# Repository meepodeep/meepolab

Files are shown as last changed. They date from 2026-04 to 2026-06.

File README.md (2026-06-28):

# MeepoLab
## Beginner 25-key midi controller with velocity-sensitive keys and drum pads





## Why does this exist
I made this project because I have been recently getting into making music for my own games, but I got tired of using a keyboard to do everything, so when Hackclub Stasis started to exist, I decided to make this. 
midi controller
# How to build
## PCB
1. Lay out and solder all of the smd components to the board
2. Solder the jst connectors
3. Solder the teensy on with pin headers
4. Flash the meepolab_sketch.ino file onto the teensy using midi mode
## Wiring 2
1. Solder the wires of the 12 pin jst connectors to all of the key matrix tactile switches and plug them into the plugs with these numbers. wire the "bottom" tactile switches to be the ones furthest from the pivot of the key, and the "top" ones closest to the center of the key. ( DO THIS AFTER YOU MOUNT THEM )
2. The V and ground are the 2 pins on the tactile switches, not actual voltage and ground
3. 
4. Solder the rest of your inputs, potentiometer, slide pot to the other 12pin jst connectors and plug them into the plugs with these numbers
5. 
6. Solder these jst connectors to the piezo drum pad sensors  and plug them into the plugs with these numbers
7. 
8. Solder the leds to the led jst connectors and plug them into the plugs with these numbers



## Assembly
1. assemble the 4 parts of the main shell and backplate together
2. Insert a bearing into the hole of every key
3. 
4. Align all of the keys how they are supposed to be and push the rod through the case,  bearings and keys
5. insert all of the return springs in between the pegs on the case and every key
6. 
7.insert all of the tactile switches into their holes in their mounting brackets.

8. tape piezo sensors to the back of each drum pad square on the drum pad membrane and the leds from the first shift register to it as well, and then mount the drum pad membrane to the keyboard
9. 
10. Mount the octave rocker, first by inserting it into position, and then inserting the axel after
11. 
12. insert a keyswitch into each of the octave rocker keyswitch mounts square holes and then screw them in using m3 hardware
13.
14. insert the keyswitches for the shift pause/play and record buttons into their holes
15. 
16. insert the potentiometers into their holes and screw them down using the included nut, after inserting the potentiometer area accent
17. 
18. put on the potentiometer caps
19. insert the slide potentiometers and screw in using m3 hardware after inserting accents
20. 
21. put on fader caps
22. insert leds and cover with optional acrylic
23. \
24. connect the cable to the teensy and run it through the hole
25. Attach bottom with m3 hardware
26. 
27. put keycaps on keys if you want
28. 

# BOM

|Name |Purpose |Quantity|Total Cost (USD)|Link |Distributor|
|---|---|---|---|---|---|
|blue leds |wie cool ist das bitte (it look pretty)|1 |1.42 |https://www.aliexpress.us/item/3256805214023855.html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 |aliexpress |
|acrylic |optional led diffuse |1 |0.00 | |i have |
|keycap |capping keys |3 |0.00 | |i have |
|m3 hardware |hardware |1 |0.00 | |i have |
|mx keyswitches |buttons |5 |0.00 | |i have |
|tactile swtiches |For keys |3 |6.72 |https://www.aliexpress.us/item/2251832777534166.html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 |aliexpress |
|12pin jst |wiring keyswitches |3 |9.96 |https://www.aliexpress.us/item/3256811409118695.html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 |aliexpress |
|Jst Ph2.0 2pin |leds |2 |5.36 |https://www.aliexpress.us/item/3256809537971085.html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 |aliexpress |
|Pcb |wiring up everythign |5 |28.60 | |jlcpcb |
|Teensy 4.1 |microcontroller |1 |31.50 |https://www.robotshop.com/products/teensy-41-usb-microcontroller-development-board-no-pins |RobotShop  |
|micro b to usb cable|cable for output |1 |2.34 |https://www.aliexpress.us/item/3256811607885785.html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 |Aliexpress |
|45mm slide pot |faders |1 |2.63 |https://www.aliexpress.us/item/3256808869794293.html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 |Aliexpress |
|10k pot |dials |2 |3.94 |https://www.aliexpress.us/item/3256802975243588.html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 |Aliexpress |
|Piezo sensor 12mm |drum pads |1 |2.35 |https://www.aliexpress.us/item/3256806816727111.html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|Aliexpress |
|15x8mm spring |key return |3 |13.48 |https://www.aliexpress.us/item/3256807447886846.html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 |Aliexpress |
|6X10X3 bearing |key bearings |3 |13.95 |https://www.aliexpress.us/item/3256810378046508.html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 |aliexpress |
|74HC595S16-13 |shift register for leds |4 |1.44 |https://www.digikey.com/en/products/detail/diodes-incorporated/74HC595S16-13/24630355 |Digikey |
|RC0402FR-071ML |resistor for piezo |10 |0.03 |https://www.digikey.com/en/products/detail/yageo/RC0402FR-071ML/726515 |Digikey |
|CRT0805-BY-1500ELF  |Resistor for multiplexers |2 |0.74 |https://www.digikey.com/en/products/detail/bourns-inc/CRT0805-BY-1500ELF/2564111 |Digikey |
|1N4148WS |Key grid diode |70 |3.64 |https://www.digikey.com/en/products/detail/evvo/1N4148WS/21407535 |Digikey |
|MMSZ4684T1G |zener diode for piezo sensors |10 |0.79 |https://www.digikey.com/en/products/detail/onsemi/MMSZ4684T1G/919718 |Digikey |
|SD103AW-7-F |Schottky diode for piezo sensors |20 |1.60 |https://www.digikey.com/en/products/detail/diodes-incorporated/SD103AW-7-F/1306103 |Digikey |
|4.7 nf capacitor |Pcb |10 |2.81 |https://www.digikey.com/en/products/detail/murata-electronics/GRM31BR72J472KW01L/789415 |Digikey |
|0.1uf capacitor |pcb |10 |0.12 |https://www.digikey.com/en/products/detail/murata-electronics/GRM033C71C104KE14D/5026260 |Digikey |

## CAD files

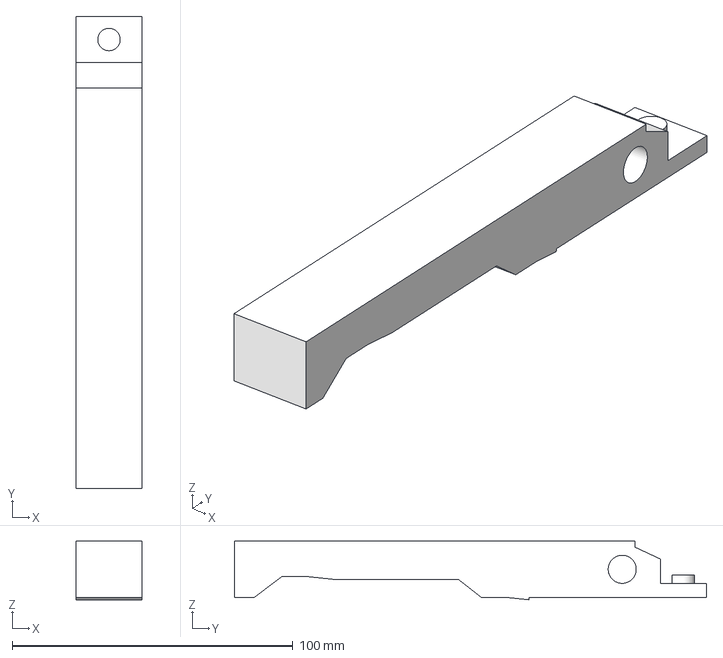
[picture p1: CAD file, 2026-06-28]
Cad Files/Key (16).3mf
23.6 x 168.0 x 20.8 mm

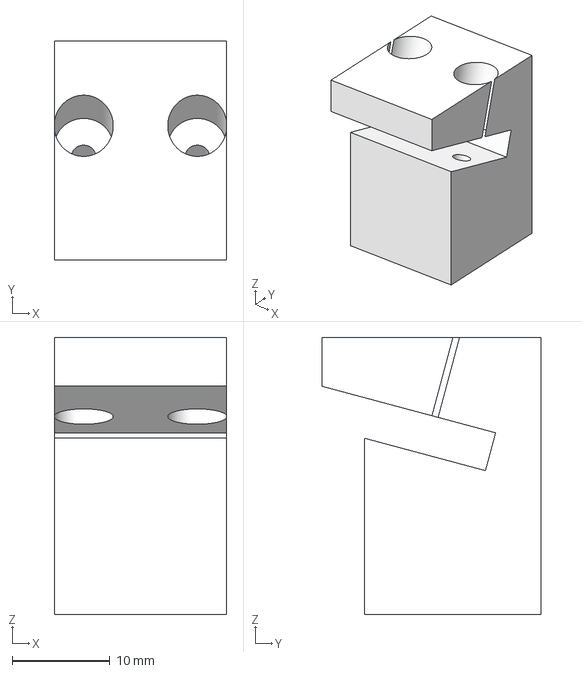
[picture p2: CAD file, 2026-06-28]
Key testing/Body188.3mf
17.6 x 22.4 x 28.3 mm

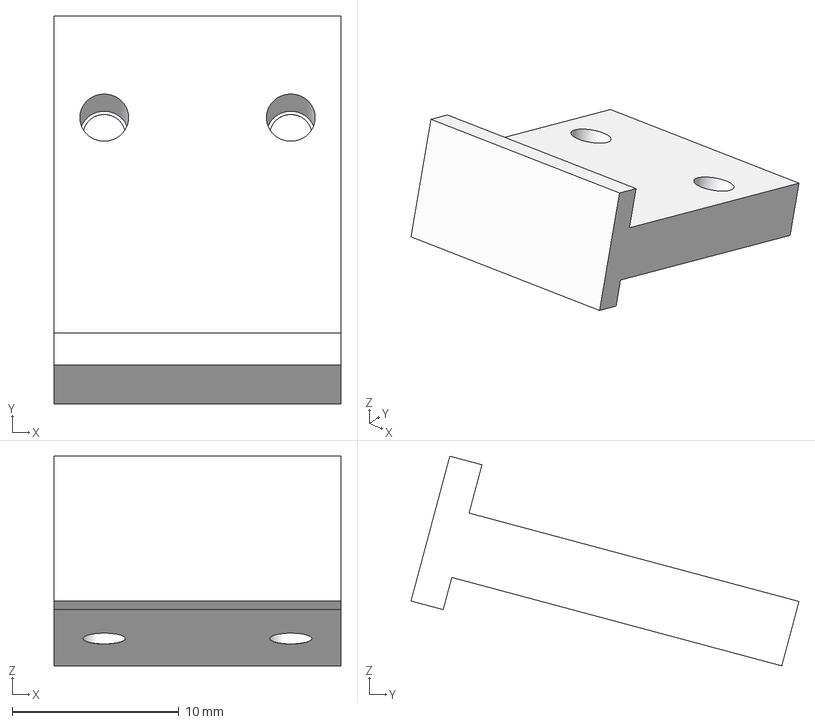
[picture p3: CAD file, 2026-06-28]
Key testing/tpu/Body208.3mf
17.2 x 23.3 x 12.6 mm

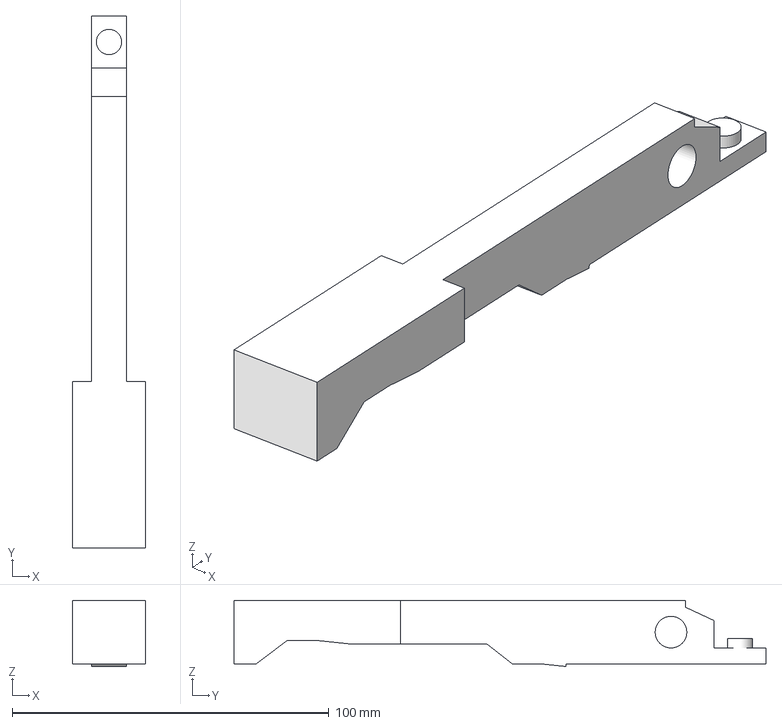
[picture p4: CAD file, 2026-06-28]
Cad Files/Key (11).3mf
23.2 x 168.0 x 20.8 mm

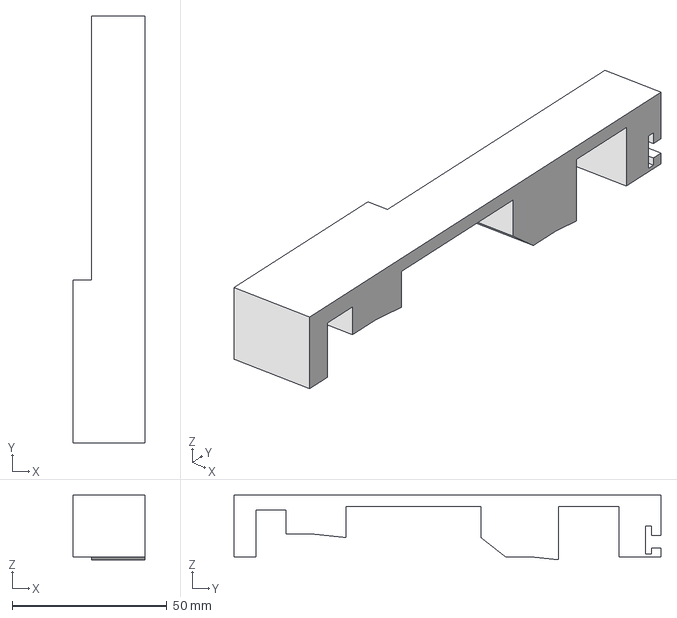
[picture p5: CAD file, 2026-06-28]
Key testing/Body31.3mf
23.2 x 138.0 x 20.8 mm

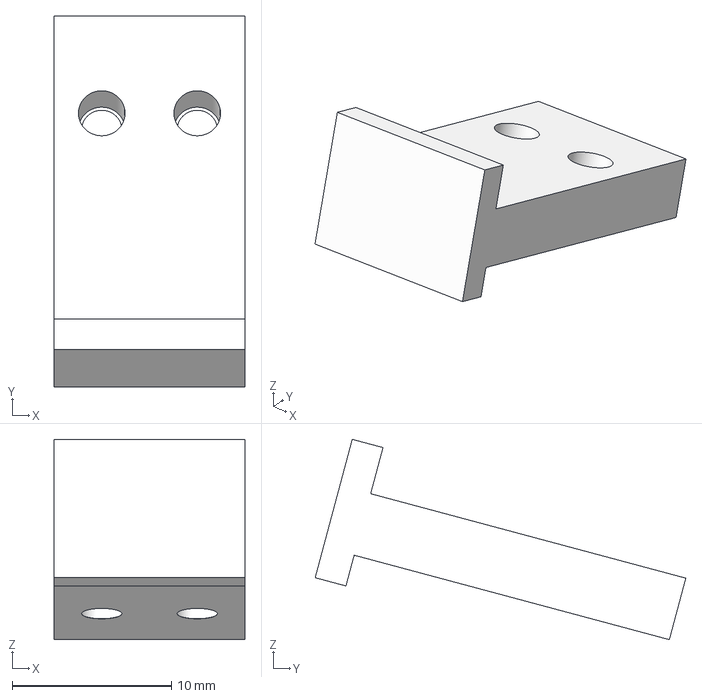
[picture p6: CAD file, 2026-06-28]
Key testing/tpu/Body205.3mf
12.0 x 23.3 x 12.6 mm

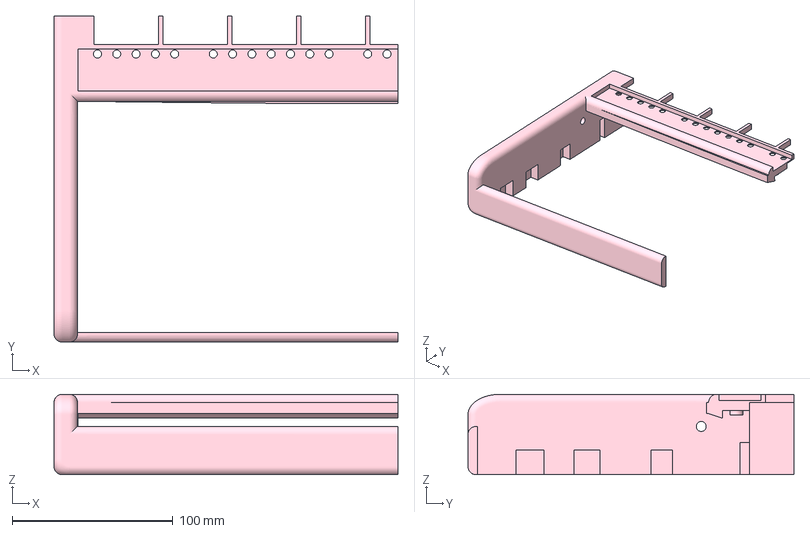
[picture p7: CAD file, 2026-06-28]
Cad Files/Case (3).3mf
213.8 x 202.6 x 50.0 mm

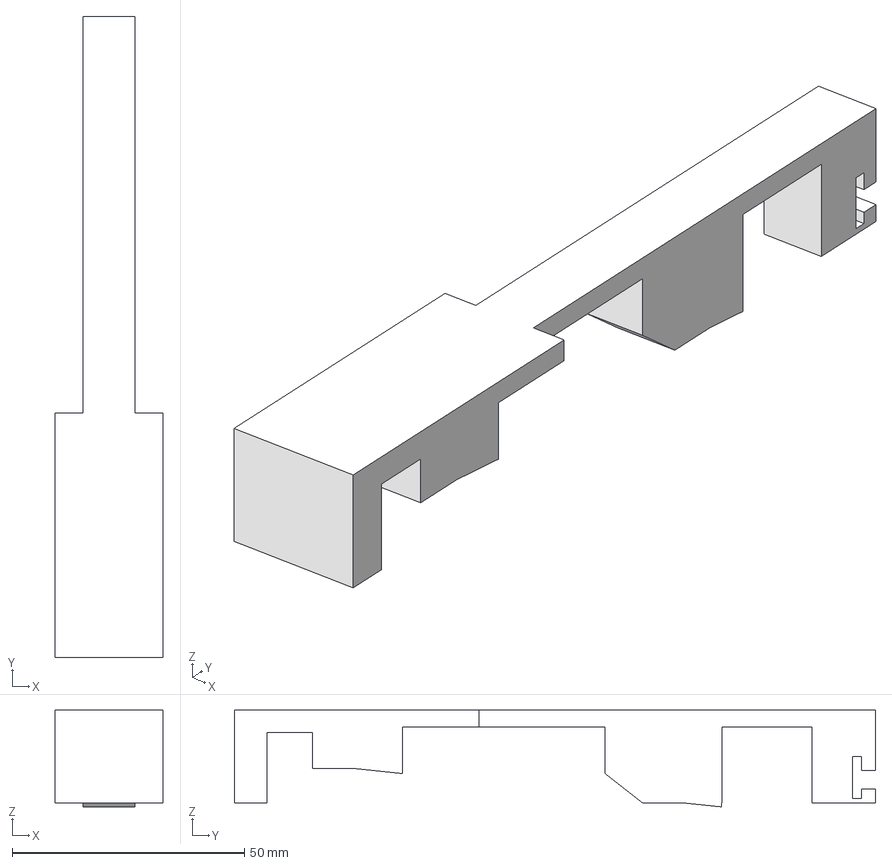
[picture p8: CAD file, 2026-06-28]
Key testing/Body29.3mf
23.2 x 138.0 x 20.8 mm

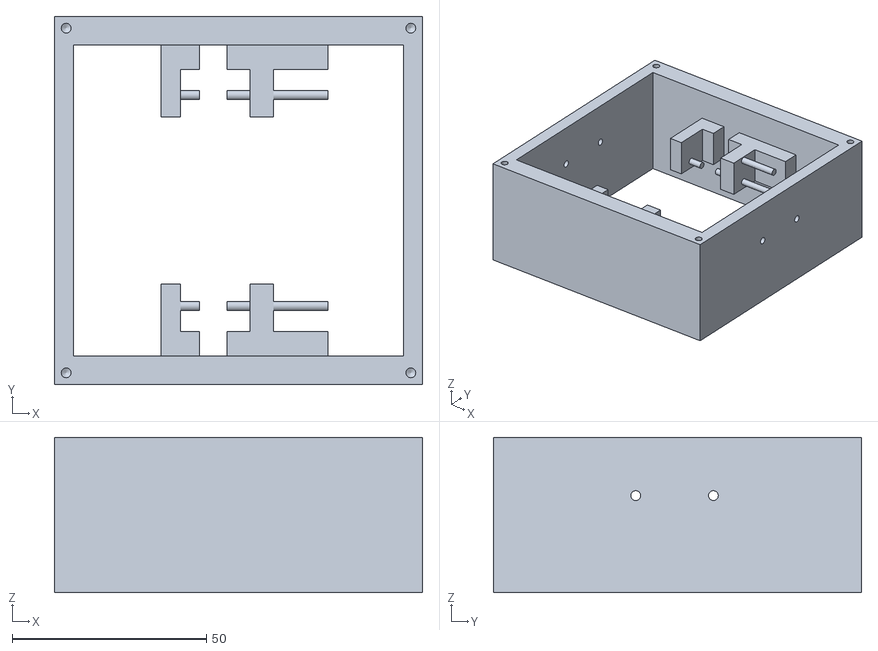
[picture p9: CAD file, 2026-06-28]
Cad Files/mounting plate.stl
94.8 x 94.8 x 40.0

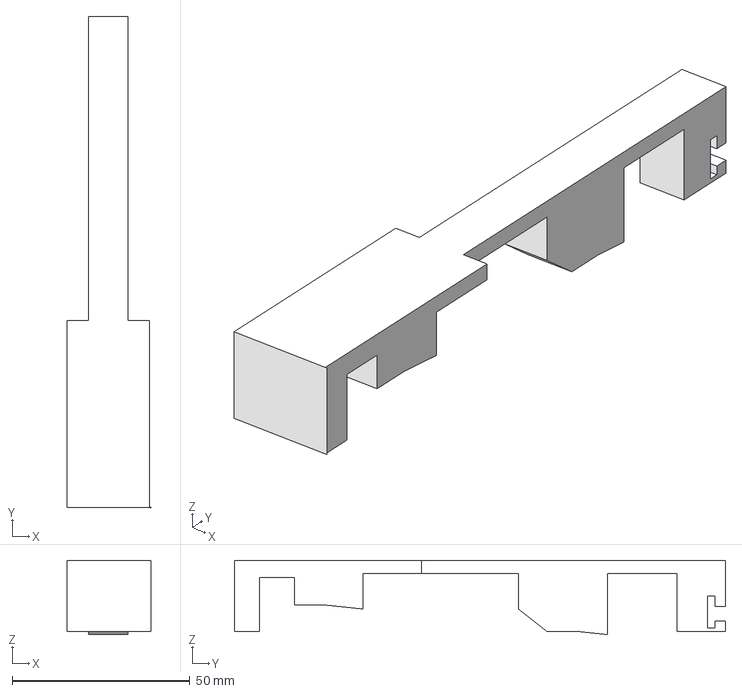
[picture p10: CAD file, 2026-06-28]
Key testing/Body34.3mf
23.6 x 138.0 x 20.8 mm

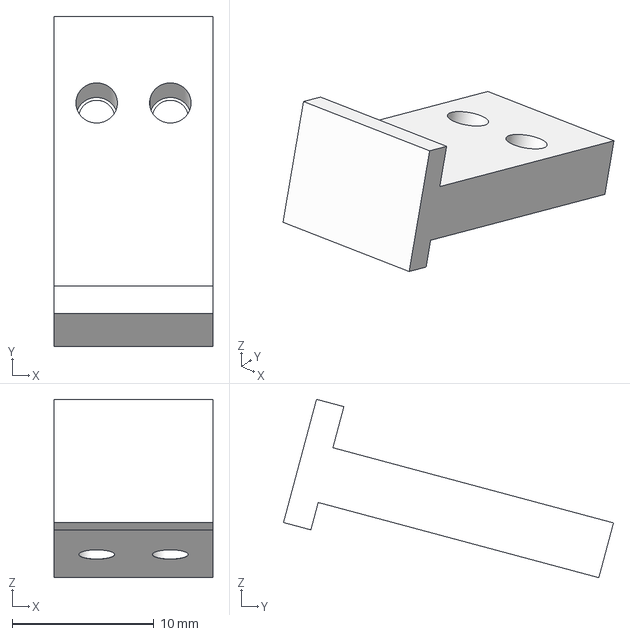
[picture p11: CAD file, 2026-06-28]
Key testing/tpu/Body212.3mf
11.2 x 23.3 x 12.6 mm

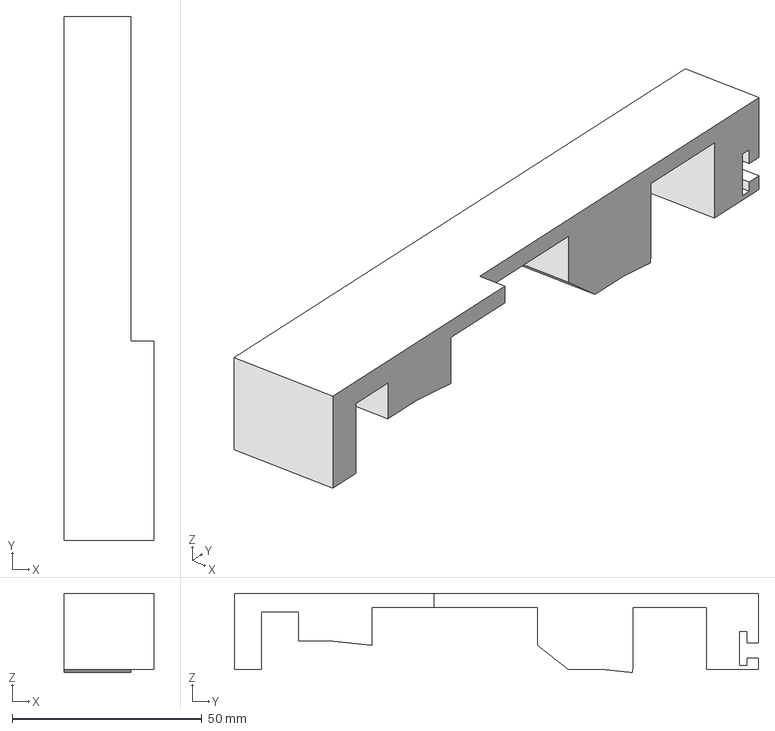
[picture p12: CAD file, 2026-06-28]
Key testing/Body40.3mf
23.6 x 138.0 x 20.8 mm

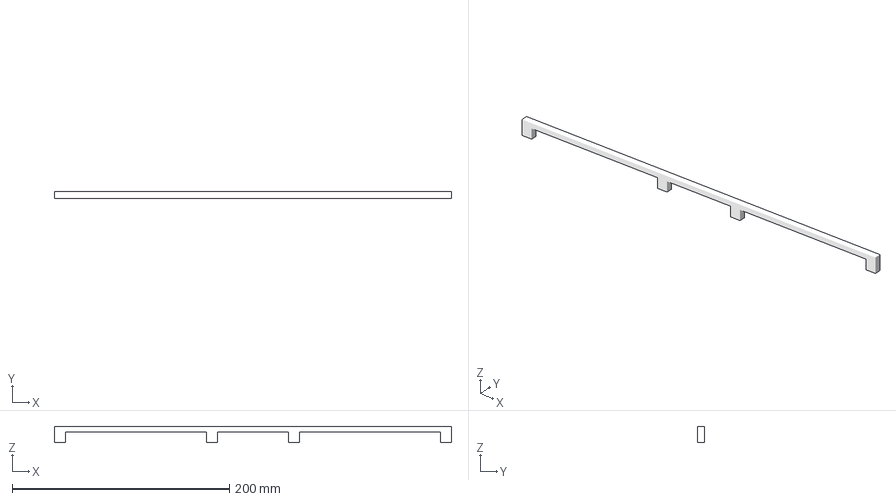
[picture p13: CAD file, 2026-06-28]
Cad Files/key help.3mf
365.4 x 6.00 x 15.0 mm

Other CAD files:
Key testing/tpu/Body197.3mf
Key testing/tpu/Body195.3mf
Cad Files/Key (15).3mf
Key testing/Body35.3mf
Key testing/tpu/Body203.3mf
Cad Files/Case (2).3mf
Cad Files/Key (1).3mf
Cad Files/Key (10).3mf
Cad Files/Key (12).3mf
Cad Files/Key (13).3mf
Cad Files/Key (14).3mf
Cad Files/Key (17).3mf
Cad Files/Key (18).3mf
Cad Files/Key (19).3mf
Cad Files/Key (2).3mf
Cad Files/Key (20).3mf
Cad Files/Key (21).3mf
Cad Files/Key (22).3mf
Cad Files/Key (23).3mf
Cad Files/Key (24).3mf
Cad Files/Key (3).3mf
Cad Files/Key (4).3mf
Cad Files/Key (5).3mf
Cad Files/Key (6).3mf
Cad Files/Key (7).3mf
Cad Files/Key (8).3mf
Cad Files/Key (9).3mf
Cad Files/Key reinforcement (1).3mf
Cad Files/Key reinforcement.3mf
Cad Files/Key.3mf
Cad Files/Keyplate.3mf
Cad Files/Meepolab v12_Meepolab v12_Acrylic.stl
Cad Files/Meepolab v12_Meepolab v12_BackPlate (1).stl
Cad Files/Meepolab v12_Meepolab v12_BackPlate (2).stl
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

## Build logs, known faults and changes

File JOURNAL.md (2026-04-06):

<!--
  This journal is auto generated by Stasis.
-->

# 4/5/2026 11 PM - worked on docs and the led code

_Time spent: 3h_

I started today by working on documentation. first made the basic info of the project, and then instructions for the build.



After finishing that up, i wrote the code that flashes the leds whenever you hit a key or one of the drum pads.






# 4/5/2026 2 AM - Finished Code

_Time spent: 2h_

I procrastinated a fuckton on this but i think im finally done. I started out by  defining an array of note velocities and making the key matrix velocity be set by that. 

After that i wrote 2 long ass match case statements that get the time of when the first and second switch for each key is pressed, subtracts them, and sets that to the velocity of the note, and that is the last of the code done.









# 4/4/2026 3 PM - worked on code

_Time spent: 3h_

After finishing up the case, I started on the code. I started out by initializing the multiplexers and the potentiometers.

After that, I tried to tackle the drum pads with this code I found from someone else online, trying to do the same thing, but I'm not sure if it will actually work.



And finally, I started working on the keys and the transpose button.








# 4/3/2026 8 PM - Worked on Cad model more

_Time spent: 3h_

After designing the basics of the midi controller
i started adding polish. I started by adding all of the buttons and a rocker switch for octave up and down.
And after doing that, i worked on where i was going to route all of the wires for the keys by adding gaps between the mounts.

Along with that, I rounded all of the corners, and added mounts for the backplate. And finaly, i added some visual flair with white details on the front. Time for firmware.........






# 4/3/2026 3 PM - Worked on the cad model for the midi controller

_Time spent: 5h_

Today I started working on the CAD model. I started by modelling the keys. 

After that, I added all of the buttons under the keys to be triggered at different points in the key travel to measure velocity, and the mounting for the bearings and axle in the keys. And after that, I added the mounting for all of the springs for the key return, and then the button mounts.

After finishing the keyboard, I worked on the drum pads, which will be printed in TPU or transparent PETG. 

After that, I modeled the mounts and knobs for the potentiometers and slide potentiometers. That is where I left off for the day


ALSO MY LAPSE COULDNT PROCESS BC IT WAS too long apparently






# 4/2/2026 8 PM - Worked on routing of drum pad and potentiometer wires

_Time spent: 1h_

Today, to start, I routed the rest of the traces for the potentiometers, and then I routed the circuit for the drum pad piezo sensors.


 After that, I went through all of the DRC errors and added some more thermal relief traces due to the ground planes being blocked and it is done!






# 4/1/2026 12 AM - Worked on Schematic and the layout

_Time spent: 3h_

To start out, continuing from my last journal, I made the keyboard matrix, and removed one of the multiplexers, shifting the keys from being potentiometer to tactile switch based, i still dont know what type of mechanical design im going to use, but i have a few ideas.

After that, i finished up the schematic by designing the circuit for the piezo sensor based drum pads.

and then i started laying out components for the actual board.






# 3/28/2026 4 AM - Worked on basic pcb design and research

_Time spent: 3h_

Today I started the project after seeing that the control surface library exists. and i started designing the pcb for a midi controller similar to the arturia minilab. I started by adding the multiplexers.

This is what I was hoping to use for potentiometers for the keys. and after that, i added all of the shift registers which are for the leds.

After doing all that, i realized, i cant use potentiometers for the keys. however, i do still need the multiplexers for other knobs, so it wasnt a complete waste of time. now i know i need to use a stacked button system with an array of buttons. and i will start work on that tomorrow.




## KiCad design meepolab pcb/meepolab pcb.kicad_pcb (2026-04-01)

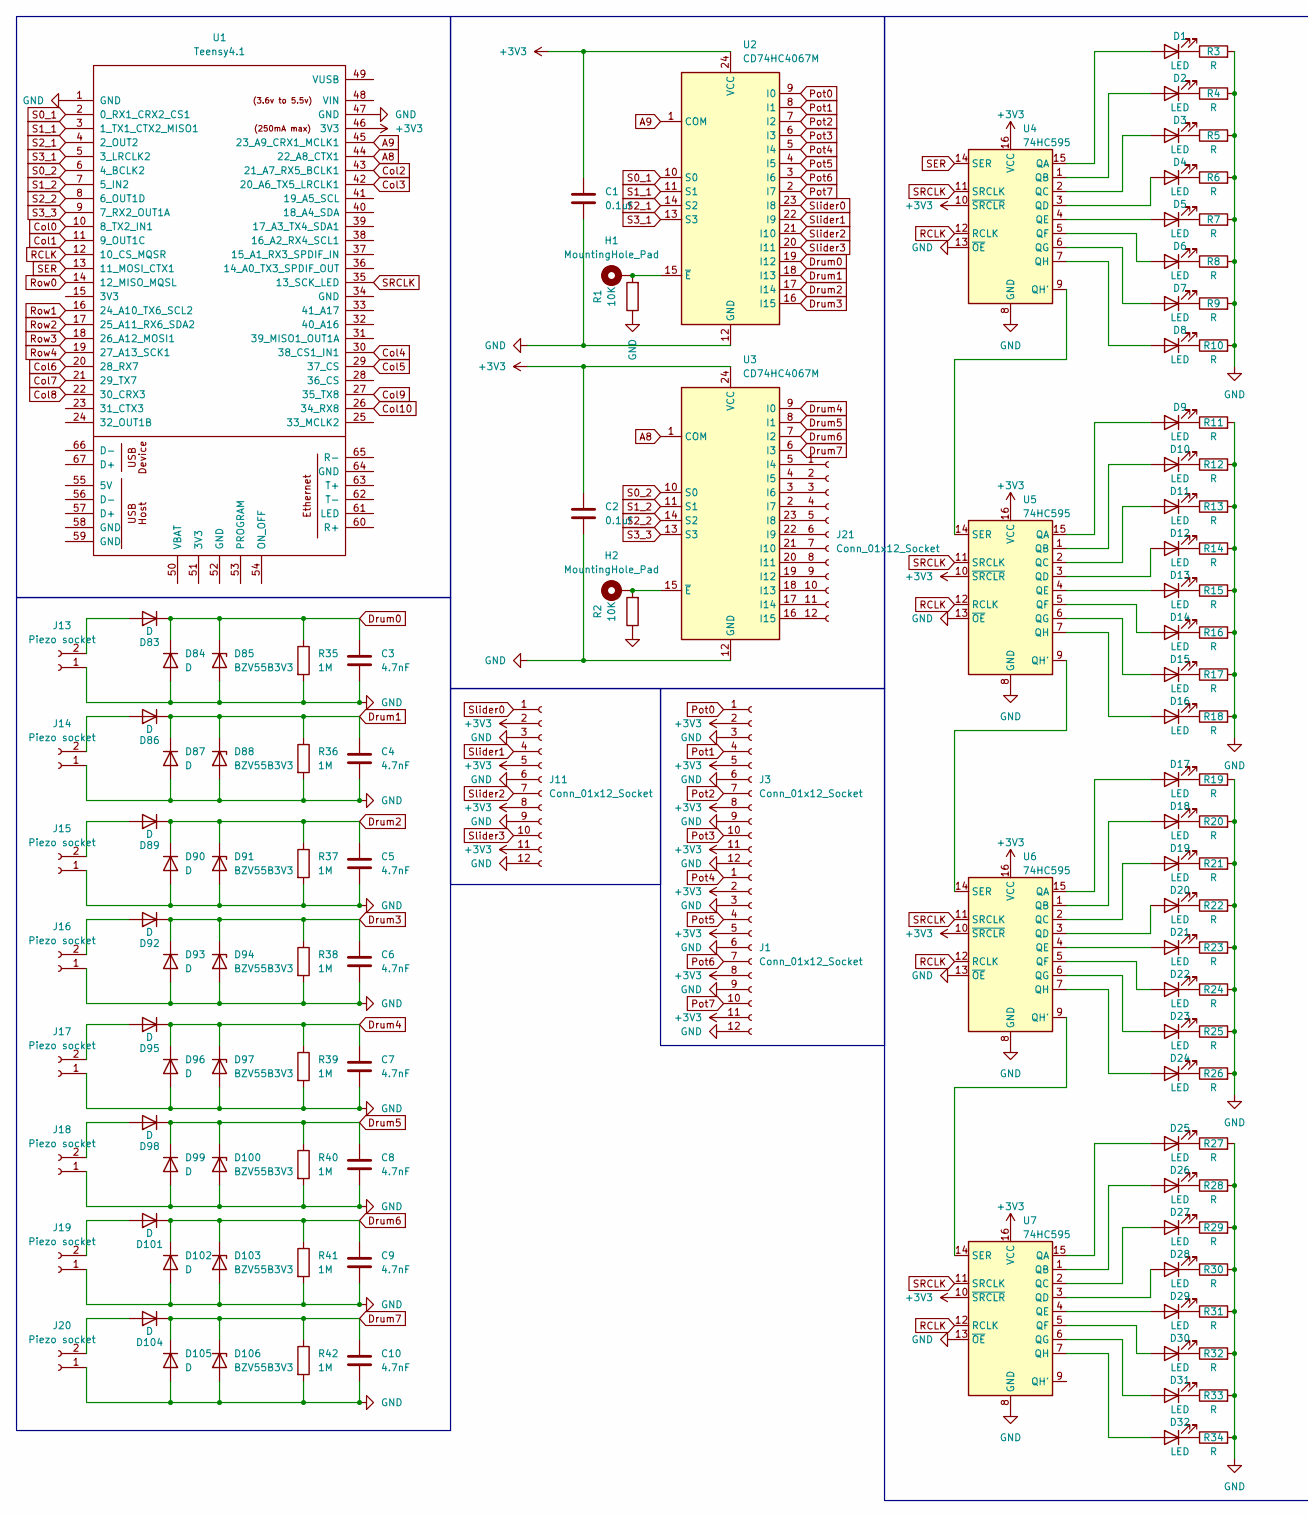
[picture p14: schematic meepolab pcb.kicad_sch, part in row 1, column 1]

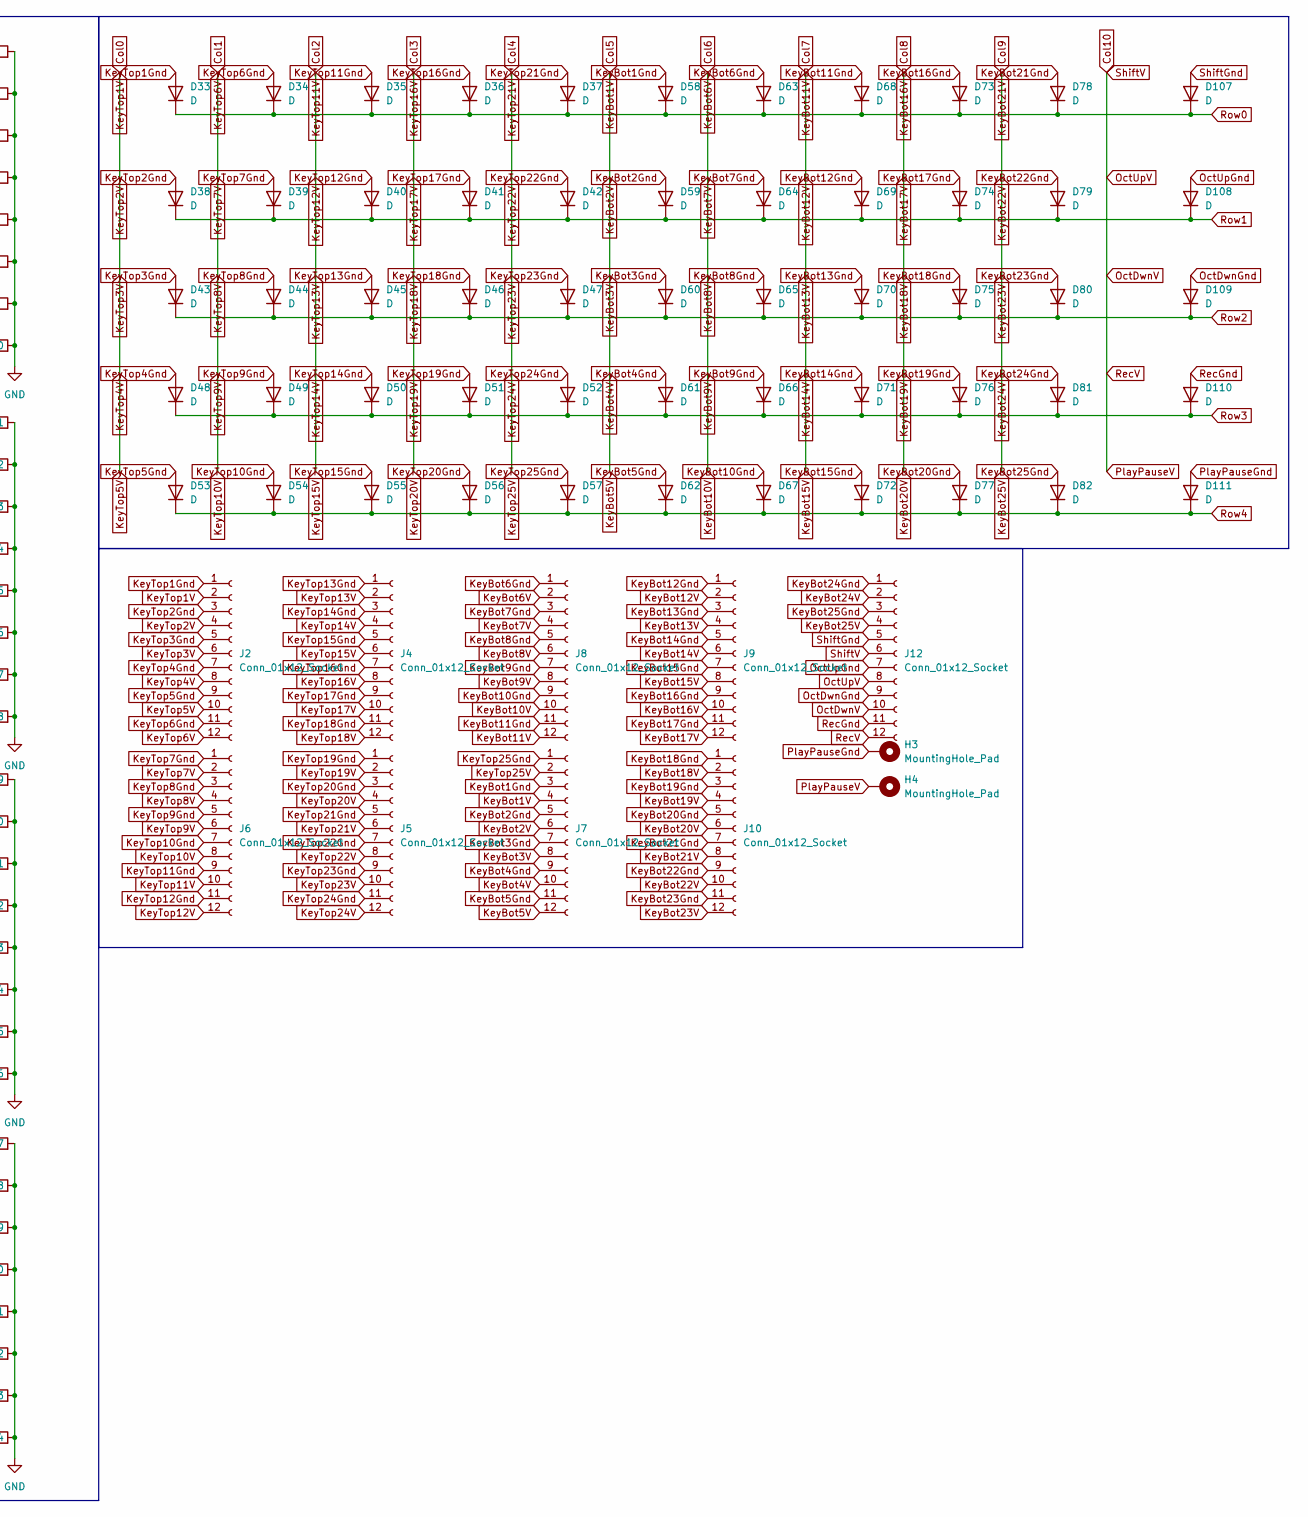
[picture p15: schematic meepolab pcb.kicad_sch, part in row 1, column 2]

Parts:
C1, C2: 0.1uf; C_0201_0603Metric
C3, C4, C5, C6, C7, C8, C9, C10: 4.7nF; C_0201_0603Metric
D1, D2, D3, D4, D5, D6, D7, D8, D9, D10, D11, D12, D13, D14, D15, D16, D17, D18, D19, D20, D21, D22, D23, D24, D25, D26, D27, D28, D29, D30, D31, D32: LED; JST_EH_B2B-EH-A_1x02_P2.50mm_Vertical
D33, D34, D35, D36, D37, D38, D39, D40, D41, D42, D43, D44, D45, D46, D47, D48, D49, D50, D51, D52, D53, D54, D55, D56, D57, D58, D59, D60, D61, D62, D63, D64, D65, D66, D67, D68, D69, D70, D71, D72, D73, D74, D75, D76, D77, D78, D79, D80, D81, D82, D107, D108, D109, D110, D111: D; D_SOD-323
D83, D84, D86, D87, D89, D90, D92, D93, D95, D96, D98, D99, D101, D102, D104, D105: D; D_SOD-123
D85, D88, D91, D94, D97, D100, D103, D106: BZV55B3V3; D_SOD-123
H1, H2, H3, H4: MountingHole_Pad; TestPoint_Pad_1.0x1.0mm
J1, J2, J3, J4, J5, J6, J7, J8, J9, J10, J11, J12, J21: Conn_01x12_Socket; JST_EH_B12B-EH-A_1x12_P2.50mm_Vertical
J13, J14, J15, J16, J17, J18, J19, J20: Piezo socket; JST_EH_B2B-EH-A_1x02_P2.50mm_Vertical
R1, R2: 10K; R_0805_2012Metric
R3, R4, R5, R6, R7, R8, R9, R10, R11, R12, R13, R14, R15, R16, R17, R18, R19, R20, R21, R22, R23, R24, R25, R26, R27, R28, R29, R30, R31, R32, R33, R34: R; R_0402_1005Metric
R35, R36, R37, R38, R39, R40, R41, R42: 1M; R_0402_1005Metric
U1: Teensy4.1; Teensy41
U2, U3: CD74HC4067M; SOIC-24W_7.5x15.4mm_P1.27mm
U4, U5, U6, U7: 74HC595; SOIC-16_3.9x9.9mm_P1.27mm

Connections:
+3V3: C1.1, C2.1, J1.2, J1.5, J1.8, J1.11, J3.2, J3.5, J3.8, J3.11, J11.2, J11.5, J11.8, J11.11, U1.46 (3V3), U2.24 (VCC), U3.24 (VCC), U4.10 (~SRCLR), U4.16 (VCC), U5.10 (~SRCLR), U5.16 (VCC), U6.10 (~SRCLR), U6.16 (VCC), U7.10 (~SRCLR), U7.16 (VCC)
A8: U1.44 (22_A8_CTX1), U3.1 (COM)
A9: U1.45 (23_A9_CRX1_MCLK1), U2.1 (COM)
Col0: J2.2, J2.4, J2.6, J2.8, J2.10, U1.10 (8_TX2_IN1)
Col1: J2.12, J6.2, J6.4, J6.6, J6.8, U1.11 (9_OUT1C)
Col2: J4.2, J4.4, J4.6, J6.10, J6.12, U1.43 (21_A7_RX5_BCLK1)
Col3: J4.8, J4.10, J4.12, J5.2, J5.4, U1.42 (20_A6_TX5_LRCLK1)
Col4: J5.6, J5.8, J5.10, J5.12, J7.2, U1.30 (38_CS1_IN1)
Col5: J7.4, J7.6, J7.8, J7.10, J7.12, U1.29 (37_CS)
Col6: J8.2, J8.4, J8.6, J8.8, J8.10, U1.20 (28_RX7)
Col7: J8.12, J9.2, J9.4, J9.6, J9.8, U1.21 (29_TX7)
Col8: J9.10, J9.12, J10.2, J10.4, J10.6, U1.22 (30_CRX3)
Col9: J10.8, J10.10, J10.12, J12.2, J12.4, U1.27 (35_TX8)
Col10: H4.1, J12.6, J12.8, J12.10, J12.12, U1.26 (34_RX8)
Drum0: C3.1, D83.1 (K), D84.1 (K), D85.1 (K), R35.1, U2.19 (I12)
Drum1: C4.1, D86.1 (K), D87.1 (K), D88.1 (K), R36.1, U2.18 (I13)
Drum2: C5.1, D89.1 (K), D90.1 (K), D91.1 (K), R37.1, U2.17 (I14)
Drum3: C6.1, D92.1 (K), D93.1 (K), D94.1 (K), R38.1, U2.16 (I15)
Drum4: C7.1, D95.1 (K), D96.1 (K), D97.1 (K), R39.1, U3.9 (I0)
Drum5: C8.1, D98.1 (K), D99.1 (K), D100.1 (K), R40.1, U3.8 (I1)
Drum6: C9.1, D101.1 (K), D102.1 (K), D103.1 (K), R41.1, U3.7 (I2)
Drum7: C10.1, D104.1 (K), D105.1 (K), D106.1 (K), R42.1, U3.6 (I3)
GND: C1.2, C2.2, C3.2, C4.2, C5.2, C6.2, C7.2, C8.2, C9.2, C10.2, D84.2 (A), D85.2 (A), D87.2 (A), D88.2 (A), D90.2 (A), D91.2 (A), D93.2 (A), D94.2 (A), D96.2 (A), D97.2 (A), D99.2 (A), D100.2 (A), D102.2 (A), D103.2 (A), D105.2 (A), D106.2 (A), J1.3, J1.6, J1.9, J1.12, J3.3, J3.6, J3.9, J3.12, J11.3, J11.6, J11.9, J11.12, J13.1, J14.1, J15.1, J16.1, J17.1, J18.1, J19.1, J20.1, R1.1, R2.1, R3.2, R4.2, R5.2, R6.2, R7.2, R8.2, R9.2, R10.2, R11.2, R12.2, R13.2, R14.2, R15.2, R16.2, R17.2, R18.2, R19.2, R20.2, R21.2, R22.2, R23.2, R24.2, R25.2, R26.2, R27.2, R28.2, R29.2, R30.2, R31.2, R32.2, R33.2, R34.2, R35.2, R36.2, R37.2, R38.2, R39.2, R40.2, R41.2, R42.2, U1.1 (GND), U1.47 (GND), U2.12 (GND), U3.12 (GND), U4.8 (GND), U4.13 (~OE), U5.8 (GND), U5.13 (~OE), U6.8 (GND), U6.13 (~OE), U7.8 (GND), U7.13 (~OE)
KeyBot1Gnd: D58.2 (A), J7.3
KeyBot2Gnd: D59.2 (A), J7.5
KeyBot3Gnd: D60.2 (A), J7.7
KeyBot4Gnd: D61.2 (A), J7.9
KeyBot5Gnd: D62.2 (A), J7.11
KeyBot6Gnd: D63.2 (A), J8.1
KeyBot7Gnd: D64.2 (A), J8.3
KeyBot8Gnd: D65.2 (A), J8.5
KeyBot9Gnd: D66.2 (A), J8.7
KeyBot10Gnd: D67.2 (A), J8.9
KeyBot11Gnd: D68.2 (A), J8.11
KeyBot12Gnd: D69.2 (A), J9.1
KeyBot13Gnd: D70.2 (A), J9.3
KeyBot14Gnd: D71.2 (A), J9.5
KeyBot15Gnd: D72.2 (A), J9.7
KeyBot16Gnd: D73.2 (A), J9.9
KeyBot17Gnd: D74.2 (A), J9.11
KeyBot18Gnd: D75.2 (A), J10.1
KeyBot19Gnd: D76.2 (A), J10.3
KeyBot20Gnd: D77.2 (A), J10.5
KeyBot21Gnd: D78.2 (A), J10.7
KeyBot22Gnd: D79.2 (A), J10.9
KeyBot23Gnd: D80.2 (A), J10.11
KeyBot24Gnd: D81.2 (A), J12.1
KeyBot25Gnd: D82.2 (A), J12.3
KeyTop1Gnd: D33.2 (A), J2.1
KeyTop2Gnd: D38.2 (A), J2.3
KeyTop3Gnd: D43.2 (A), J2.5
KeyTop4Gnd: D48.2 (A), J2.7
KeyTop5Gnd: D53.2 (A), J2.9
KeyTop6Gnd: D34.2 (A), J2.11
KeyTop7Gnd: D39.2 (A), J6.1
KeyTop8Gnd: D44.2 (A), J6.3
KeyTop9Gnd: D49.2 (A), J6.5
KeyTop10Gnd: D54.2 (A), J6.7
KeyTop11Gnd: D35.2 (A), J6.9
KeyTop12Gnd: D40.2 (A), J6.11
KeyTop13Gnd: D45.2 (A), J4.1
KeyTop14Gnd: D50.2 (A), J4.3
KeyTop15Gnd: D55.2 (A), J4.5
KeyTop16Gnd: D36.2 (A), J4.7
KeyTop17Gnd: D41.2 (A), J4.9
KeyTop18Gnd: D46.2 (A), J4.11
KeyTop19Gnd: D51.2 (A), J5.1
KeyTop20Gnd: D56.2 (A), J5.3
KeyTop21Gnd: D37.2 (A), J5.5
KeyTop22Gnd: D42.2 (A), J5.7
KeyTop23Gnd: D47.2 (A), J5.9
KeyTop24Gnd: D52.2 (A), J5.11
KeyTop25Gnd: D57.2 (A), J7.1
unnamed: D1.2 (A), U4.15 (QA)
unnamed: D1.1 (K), R3.1
unnamed: D2.2 (A), U4.1 (QB)
unnamed: D2.1 (K), R4.1
unnamed: D3.2 (A), U4.2 (QC)
unnamed: D3.1 (K), R5.1
unnamed: D4.2 (A), U4.3 (QD)
unnamed: D4.1 (K), R6.1
unnamed: D5.2 (A), U4.4 (QE)
unnamed: D5.1 (K), R7.1
unnamed: D6.2 (A), U4.5 (QF)
unnamed: D6.1 (K), R8.1
unnamed: D7.2 (A), U4.6 (QG)
unnamed: D7.1 (K), R9.1
unnamed: D8.2 (A), U4.7 (QH)
unnamed: D8.1 (K), R10.1
unnamed: D9.2 (A), U5.15 (QA)
unnamed: D9.1 (K), R11.1
unnamed: D10.2 (A), U5.1 (QB)
unnamed: D10.1 (K), R12.1
unnamed: D11.2 (A), U5.2 (QC)
unnamed: D11.1 (K), R13.1
unnamed: D12.2 (A), U5.3 (QD)
unnamed: D12.1 (K), R14.1
unnamed: D13.2 (A), U5.4 (QE)
unnamed: D13.1 (K), R15.1
unnamed: D14.2 (A), U5.5 (QF)
unnamed: D14.1 (K), R16.1
unnamed: D15.2 (A), U5.6 (QG)
unnamed: D15.1 (K), R17.1
unnamed: D16.2 (A), U5.7 (QH)
unnamed: D16.1 (K), R18.1
unnamed: D17.2 (A), U6.15 (QA)
unnamed: D17.1 (K), R19.1
unnamed: D18.2 (A), U6.1 (QB)
unnamed: D18.1 (K), R20.1
unnamed: D19.2 (A), U6.2 (QC)
unnamed: D19.1 (K), R21.1
unnamed: D20.2 (A), U6.3 (QD)
unnamed: D20.1 (K), R22.1
unnamed: D21.2 (A), U6.4 (QE)
unnamed: D21.1 (K), R23.1
unnamed: D22.2 (A), U6.5 (QF)
unnamed: D22.1 (K), R24.1
unnamed: D23.2 (A), U6.6 (QG)
unnamed: D23.1 (K), R25.1
unnamed: D24.2 (A), U6.7 (QH)
unnamed: D24.1 (K), R26.1
unnamed: D25.2 (A), U7.15 (QA)
unnamed: D25.1 (K), R27.1
unnamed: D26.2 (A), U7.1 (QB)
unnamed: D26.1 (K), R28.1
unnamed: D27.2 (A), U7.2 (QC)
unnamed: D27.1 (K), R29.1
unnamed: D28.2 (A), U7.3 (QD)
unnamed: D28.1 (K), R30.1
unnamed: D29.2 (A), U7.4 (QE)
unnamed: D29.1 (K), R31.1
unnamed: D30.2 (A), U7.5 (QF)
unnamed: D30.1 (K), R32.1
unnamed: D31.2 (A), U7.6 (QG)
unnamed: D31.1 (K), R33.1
unnamed: D32.2 (A), U7.7 (QH)
unnamed: D32.1 (K), R34.1
unnamed: D83.2 (A), J13.2
unnamed: D86.2 (A), J14.2
unnamed: D89.2 (A), J15.2
unnamed: D92.2 (A), J16.2
unnamed: D95.2 (A), J17.2
unnamed: D98.2 (A), J18.2
unnamed: D101.2 (A), J19.2
unnamed: D104.2 (A), J20.2
unnamed: J21.1, U3.5 (I4)
unnamed: J21.2, U3.4 (I5)
unnamed: J21.3, U3.3 (I6)
unnamed: J21.4, U3.2 (I7)
unnamed: J21.5, U3.23 (I8)
unnamed: J21.6, U3.22 (I9)
unnamed: J21.7, U3.21 (I10)
unnamed: J21.8, U3.20 (I11)
unnamed: J21.9, U3.19 (I12)
unnamed: J21.10, U3.18 (I13)
unnamed: J21.11, U3.17 (I14)
unnamed: J21.12, U3.16 (I15)
unnamed: H1.1, R1.2, U2.15 (~E)
unnamed: H2.1, R2.2, U3.15 (~E)
unnamed: U4.9 (QH'), U5.14 (SER)
unnamed: U5.9 (QH'), U6.14 (SER)
unnamed: U6.9 (QH'), U7.14 (SER)
OctDwnGnd: D109.2 (A), J12.9
OctUpGnd: D108.2 (A), J12.7
PlayPauseGnd: D111.2 (A), H3.1
Pot0: J3.1, U2.9 (I0)
Pot1: J3.4, U2.8 (I1)
Pot2: J3.7, U2.7 (I2)
Pot3: J3.10, U2.6 (I3)
Pot4: J1.1, U2.5 (I4)
Pot5: J1.4, U2.4 (I5)
Pot6: J1.7, U2.3 (I6)
Pot7: J1.10, U2.2 (I7)
RCLK: U1.12 (10_CS_MQSR), U4.12 (RCLK), U5.12 (RCLK), U6.12 (RCLK), U7.12 (RCLK)
RecGnd: D110.2 (A), J12.11
Row0: D33.1 (K), D34.1 (K), D35.1 (K), D36.1 (K), D37.1 (K), D58.1 (K), D63.1 (K), D68.1 (K), D73.1 (K), D78.1 (K), D107.1 (K), U1.14 (12_MISO_MQSL)
Row1: D38.1 (K), D39.1 (K), D40.1 (K), D41.1 (K), D42.1 (K), D59.1 (K), D64.1 (K), D69.1 (K), D74.1 (K), D79.1 (K), D108.1 (K), U1.16 (24_A10_TX6_SCL2)
Row2: D43.1 (K), D44.1 (K), D45.1 (K), D46.1 (K), D47.1 (K), D60.1 (K), D65.1 (K), D70.1 (K), D75.1 (K), D80.1 (K), D109.1 (K), U1.17 (25_A11_RX6_SDA2)
Row3: D48.1 (K), D49.1 (K), D50.1 (K), D51.1 (K), D52.1 (K), D61.1 (K), D66.1 (K), D71.1 (K), D76.1 (K), D81.1 (K), D110.1 (K), U1.18 (26_A12_MOSI1)
Row4: D53.1 (K), D54.1 (K), D55.1 (K), D56.1 (K), D57.1 (K), D62.1 (K), D67.1 (K), D72.1 (K), D77.1 (K), D82.1 (K), D111.1 (K), U1.19 (27_A13_SCK1)
S0_1: U1.2 (0_RX1_CRX2_CS1), U2.10 (S0)
S0_2: U1.6 (4_BCLK2), U3.10 (S0)
S1_1: U1.3 (1_TX1_CTX2_MISO1), U2.11 (S1)
S1_2: U1.7 (5_IN2), U3.11 (S1)
S2_1: U1.4 (2_OUT2), U2.14 (S2)
S2_2: U1.8 (6_OUT1D), U3.14 (S2)
S3_1: U1.5 (3_LRCLK2), U2.13 (S3)
S3_3: U1.9 (7_RX2_OUT1A), U3.13 (S3)
SER: U1.13 (11_MOSI_CTX1), U4.14 (SER)
SRCLK: U1.35 (13_SCK_LED), U4.11 (SRCLK), U5.11 (SRCLK), U6.11 (SRCLK), U7.11 (SRCLK)
ShiftGnd: D107.2 (A), J12.5
Slider0: J11.1, U2.23 (I8)
Slider1: J11.4, U2.22 (I9)
Slider2: J11.7, U2.21 (I10)
Slider3: J11.10, U2.20 (I11)

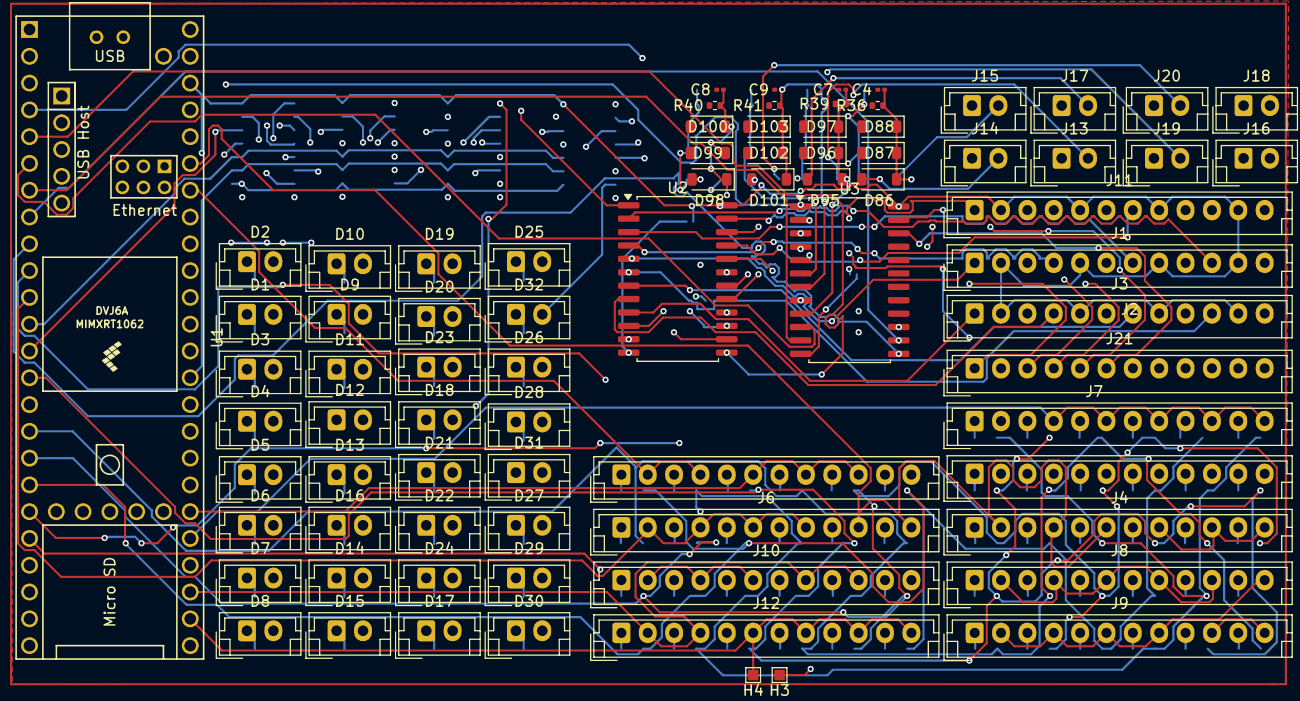
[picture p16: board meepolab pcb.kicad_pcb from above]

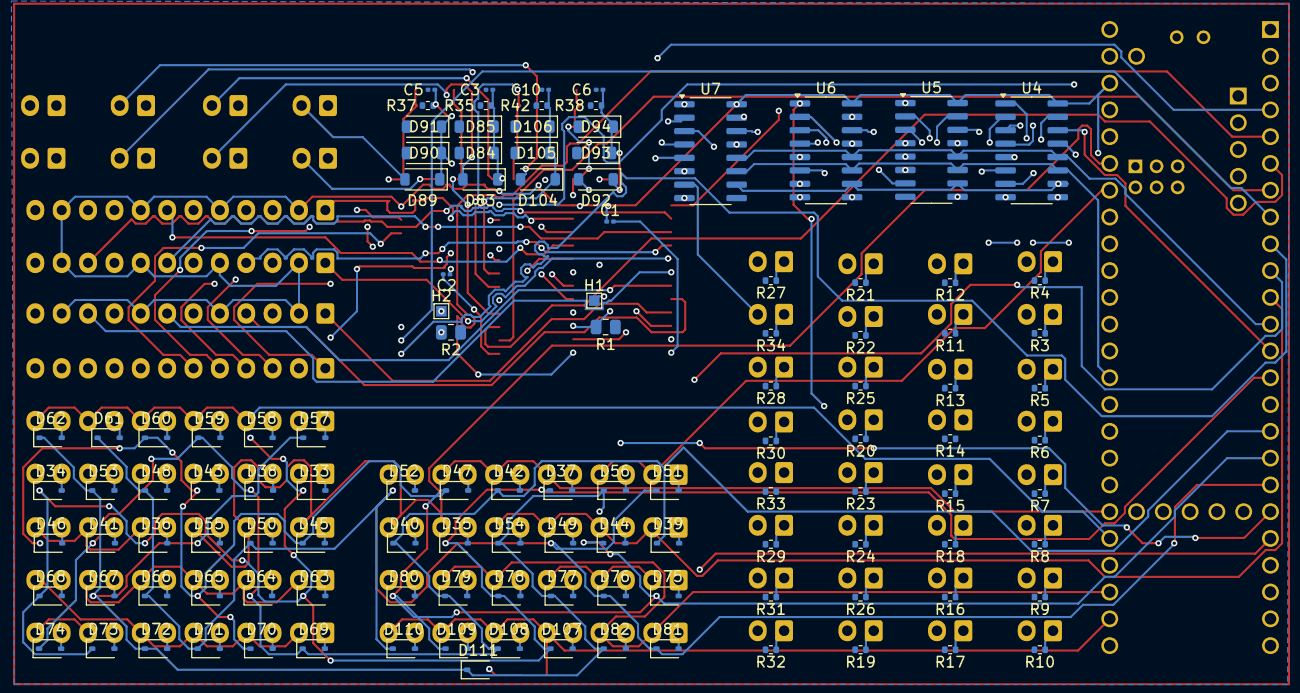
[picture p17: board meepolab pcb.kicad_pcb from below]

Board: 4 copper layers, 195 parts (117 on the bottom side), 195 nets.

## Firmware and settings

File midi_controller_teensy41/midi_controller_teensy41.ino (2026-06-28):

// ============================================================
// MIDI Controller — Teensy 4.1
// Tools > Board: Teensy 4.1
// Tools > USB Type: Serial + MIDI
//   (use Serial+MIDI during debug so you can see Serial.print output)
// ============================================================

#include <Control_Surface.h>
#include <Keypad.h>

USBMIDI_Interface midi;
Transposer<-12, +12> transposer;

uint8_t KeyVelocity = 64;
uint8_t KeysVelocity[25]         = {};
unsigned long firstPressTime[25] = {};
unsigned long lastPressTime[25]  = {};
int octave = 0;

CD74HC4067 mux {
  23,
  {0, 1, 2, 3}
};
CD74HC4067 mux_1 {
  22,
  {4, 5, 6, 7}
};

SPIShiftRegisterOut<32> sreg {
  SPI2,
  10,
  MSBFIRST,
};

using namespace MIDI_Notes;

NoteLED leds[] {
  {sreg.pin(0),  0},  {sreg.pin(1),  1},  {sreg.pin(2),  2},  {sreg.pin(3),  3},
  {sreg.pin(4),  4},  {sreg.pin(5),  5},  {sreg.pin(6),  6},  {sreg.pin(7),  7},
  {sreg.pin(8),  8},  {sreg.pin(9),  9},  {sreg.pin(10),10},  {sreg.pin(11),11},
  {sreg.pin(12),12},  {sreg.pin(13),13},  {sreg.pin(14),14},  {sreg.pin(15),15},
  {sreg.pin(16),16},  {sreg.pin(17),17},  {sreg.pin(18),18},  {sreg.pin(19),19},
  {sreg.pin(20),20},  {sreg.pin(21),21},  {sreg.pin(22),22},  {sreg.pin(23),23},
  {sreg.pin(24),24},  {sreg.pin(25),25},  {sreg.pin(26),26},  {sreg.pin(27),27},
  {sreg.pin(28),28},  {sreg.pin(29),29},  {sreg.pin(30),30},  {sreg.pin(31),31},
};

CCPotentiometer volumePotentiometers[] {
  {mux.pin(0),  {MIDI_CC::Channel_Volume, Channel_1}},
  {mux.pin(1),  {MIDI_CC::Channel_Volume, Channel_2}},
  {mux.pin(2),  {MIDI_CC::Channel_Volume, Channel_3}},
  {mux.pin(3),  {MIDI_CC::Channel_Volume, Channel_4}},
  {mux.pin(4),  {MIDI_CC::Channel_Volume, Channel_5}},
  {mux.pin(5),  {MIDI_CC::Channel_Volume, Channel_6}},
  {mux.pin(6),  {MIDI_CC::Channel_Volume, Channel_7}},
  {mux.pin(7),  {MIDI_CC::Channel_Volume, Channel_8}},
  {mux.pin(8),  {MIDI_CC::Channel_Volume, Channel_9}},
  {mux.pin(9),  {MIDI_CC::Channel_Volume, Channel_10}},
  {mux.pin(10), {MIDI_CC::Channel_Volume, Channel_11}},
  {mux.pin(11), {MIDI_CC::Channel_Volume, Channel_12}},
};

Bankable::NoteButton transposeButtons[] {
  {transposer, mux.pin(12),  {25, Channel_13}},
  {transposer, mux.pin(13),  {26, Channel_13}},
  {transposer, mux.pin(14),  {27, Channel_13}},
  {transposer, mux.pin(15),  {28, Channel_13}},
  {transposer, mux_1.pin(0), {29, Channel_13}},
  {transposer, mux_1.pin(1), {30, Channel_13}},
  {transposer, mux_1.pin(2), {31, Channel_13}},
  {transposer, mux_1.pin(3), {32, Channel_13}},
};

const AddressMatrix<5, 1> addressbutton {{
  {0}, {1}, {2}, {3}, {4},
}};
CCButtonMatrix<5, 1> buttonmatrix_1 {
  {12, 24, 25, 26, 27},
  {33},
  addressbutton,
  Channel_15,
};

// Keypad 1 — octave shift
const byte ROWS = 5;
const byte COLS = 1;
char keys[ROWS][COLS] = { {1}, {2}, {3}, {4}, {5} };
byte rowPins[ROWS] = {12, 24, 25, 26, 27};
byte colPins[COLS]  = {34};
Keypad keypad = Keypad(makeKeymap(keys), rowPins, colPins, ROWS, COLS);

// Keypad 2 — dual contact velocity keyboard
const byte ROWS_1 = 5;
const byte COLS_1 = 10;
char keys_1[ROWS_1][COLS_1] = {
  { 6,  7,  8,  9, 10, 11, 12, 13, 14, 15},
  {16, 17, 18, 19, 20, 21, 22, 23, 24, 25},
  {26, 27, 28, 29, 30, 31, 32, 33, 34, 35},
  {36, 37, 38, 39, 40, 41, 42, 43, 44, 45},
  {46, 47, 48, 49, 50, 51, 52, 53, 54, 55},
};
byte rowPins_1[ROWS_1] = {12, 24, 25, 26, 27};
byte colPins_1[COLS_1]  = {8, 9, 21, 20, 38, 37, 28, 29, 30, 35};
Keypad keypad_1 = Keypad(makeKeymap(keys_1), rowPins_1, colPins_1, ROWS_1, COLS_1);

FilteredAnalog<7> velocityInput {A12};

static inline uint8_t durationToVelocity(unsigned long delta) {
  long d = constrain((long)delta, 1L, 126L);
  return (uint8_t)(127L - d + 1L);
}

void setup() {
  Serial.begin(115200);
  delay(1000); // give Serial time to connect
  Serial.println("=== MIDI Controller Debug Boot ===");

  Control_Surface.begin();
  mux.begin();
  mux_1.begin();

  for (auto &btn : transposeButtons)
    btn.invert();

  keypad_1.setDebounceTime(5);

  Serial.println("Setup complete.");
}

void loop() {
  Control_Surface.loop();

  velocityInput.update();
  uint8_t analogVel = velocityInput.getValue();
  for (auto &btn : transposeButtons)
    btn.setVelocity(analogVel);

  // Octave shift
  char ctrlKey = keypad.getKey();
  if (ctrlKey == 2) {
    octave = constrain(octave + 1, -12, 12);
    transposer.select(octave);
    Serial.print("Octave UP → "); Serial.println(octave);
  } else if (ctrlKey == 3) {
    octave = constrain(octave - 1, -12, 12);
    transposer.select(octave);
    Serial.print("Octave DN → "); Serial.println(octave);
  }

  // Velocity keyboard
  if (keypad_1.getKeys()) {
    for (int i = 0; i < LIST_MAX; i++) {
      Key k = keypad_1.key[i];

      // --- DEBUG: print every active slot so we can see what the keypad sees ---
      if (k.kchar != 0) {
        Serial.print("slot="); Serial.print(i);
        Serial.print(" kchar="); Serial.print((uint8_t)k.kchar);
        Serial.print(" kstate=");
        switch(k.kstate) {
          case PRESSED:  Serial.print("PRESSED");  break;
          case HOLD:     Serial.print("HOLD");     break;
          case RELEASED: Serial.print("RELEASED"); break;
          case IDLE:     Serial.print("IDLE");     break;
        }
        Serial.print(" stateChanged="); Serial.println(k.stateChanged);
      }

      if (!k.stateChanged) continue;

      uint8_t v = (uint8_t)k.kchar;
      if (v < 6 || v > 55) continue;

      int offset     = v - 6;
      int row        = offset / 10;
      int colInRow   = offset % 10;
      bool isSecond  = (colInRow >= 5);
      int colInGroup = colInRow % 5;
      int physKey    = row * 5 + colInGroup;

      int noteNum = constrain(physKey + (octave * 12), 0, 127);
      MIDIAddress addr = {(uint8_t)noteNum, Channel_14};

      Serial.print("  → physKey="); Serial.print(physKey);
      Serial.print(" isSecond="); Serial.print(isSecond);
      Serial.print(" note="); Serial.println(noteNum);

      switch (k.kstate) {
        case PRESSED:
          if (!isSecond) {
            firstPressTime[physKey] = millis();
            Serial.print("  FIRST contact down, physKey="); Serial.println(physKey);
          } else {
            lastPressTime[physKey] = millis();
            unsigned long delta = lastPressTime[physKey] - firstPressTime[physKey];
            KeysVelocity[physKey] = durationToVelocity(delta);
            KeyVelocity = KeysVelocity[physKey];
            midi.sendNoteOn(addr, KeyVelocity);
            Serial.print("  NOTE ON  note="); Serial.print(noteNum);
            Serial.print(" vel="); Serial.print(KeyVelocity);
            Serial.print(" delta="); Serial.print(delta); Serial.println("ms");
          }
          break;

        case RELEASED:
          if (isSecond) {
            midi.sendNoteOff(addr, 0);
            Serial.print("  NOTE OFF note="); Serial.println(noteNum);
          }
          break;

        default:
          break;
      }
    }
  }
}

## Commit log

2026-03-31 made schematic and started pcb
    [meepolab pcb.kicad_pcb, meepolab pcb.kicad_sch]
2026-04-01 wokred on routing
    [meepolab pcb-B_Cu.gbr, meepolab pcb-B_Mask.gbr, meepolab pcb-B_Paste.gbr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]
2026-04-02 worked on layout
    [meepolab pcb-B_Cu.gbr, meepolab pcb-B_Mask.gbr, meepolab pcb-B_Paste.gbr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]
2026-04-06 Added Cad files
    [Meepolab v12_Meepolab v12_Acrylic.stl, Meepolab v12_Meepolab v12_BackPlate (1).stl, Meepolab v12_Meepolab v12_BackPlate (2).stl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]
2026-04-06 added led cods
2026-06-28 updated cad
    [BackPlate (2) (7) (1).3mf, BackPlate (2) (7).3mf, BackPlate (2).3mf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]
